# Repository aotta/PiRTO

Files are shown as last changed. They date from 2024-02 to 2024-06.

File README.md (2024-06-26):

# PiRTO

RTO-Cart porting to Raspberry PI Pico board, with on-screen menu for selecting files.

WARNING! PiRTO was developed and tested with PAL consoles, but for NTSC you need to use the .NTSC firmware that include longer delays for NTSC console

Assembly notes:
Use only 74lvc245 IC, not LVC ones are not 3,3 tolerant and may damage your Pico.
For SMD pcb version: added 3 jumper, connect 3v3 and Gnd ones, but leave open Shield jumper, connecting to Gnd seems shorting some Pico chinese clones.

Solder the microSD arduino shields on BOTTOM of the board, BEFORE you solder the Pico. Cut the pin to avoid they touche the Pico board on other sides.

Error codes (number of led flashes every second then 2 seconds pause):

1 blinks: Files too big  

2 blinks: Verify BIN files error   

3 blinks: [mapping] not found in CFG error

4 blinks: Card not initialized

5 blinks: Error opening Root

6 blinks: Map CFG error

1 blink every 800 ms is business as usual

More infor on:
https://forums.atariage.com/topic/360687-pirto-preview-new-rto-multicart-powered-by-raspberry-pico/

https://forums.atariage.com/topic/346024-intellivision-rto-multicart-new-multicart/

## Ver. 1.1 Upgrade
New version doesn't use anymore hardcoded delay in bus cycles, so it should work for every Intellivision (NTSC,PAL or SECAM).
I included the uf2 firmware in binaries folder. 
Note: with this version some games with more than 8/9 map pages (i.e. Antartic Tale, Wizard of War, etc.) don't work. Use 1.0 if you have no timing issues.

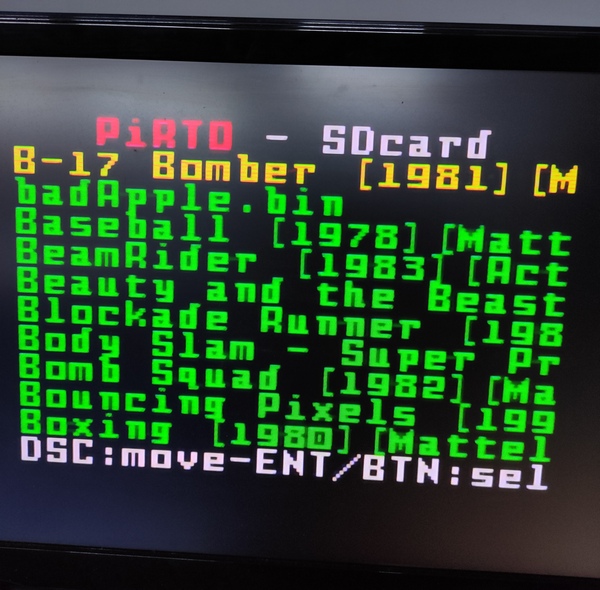
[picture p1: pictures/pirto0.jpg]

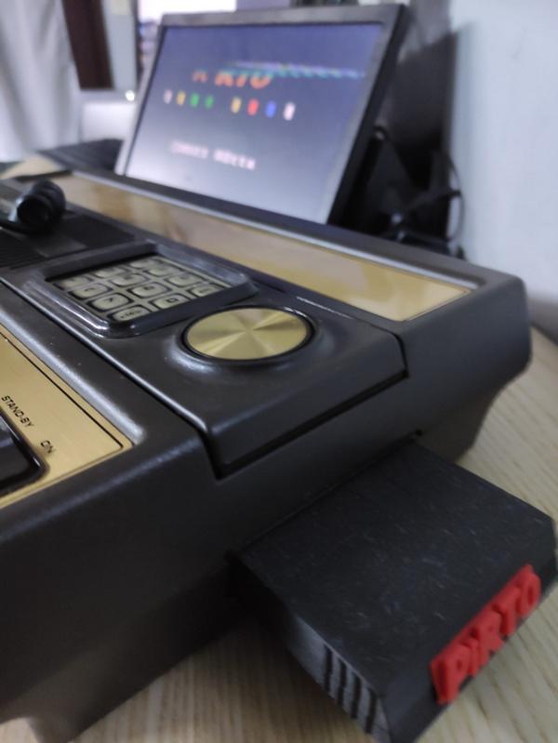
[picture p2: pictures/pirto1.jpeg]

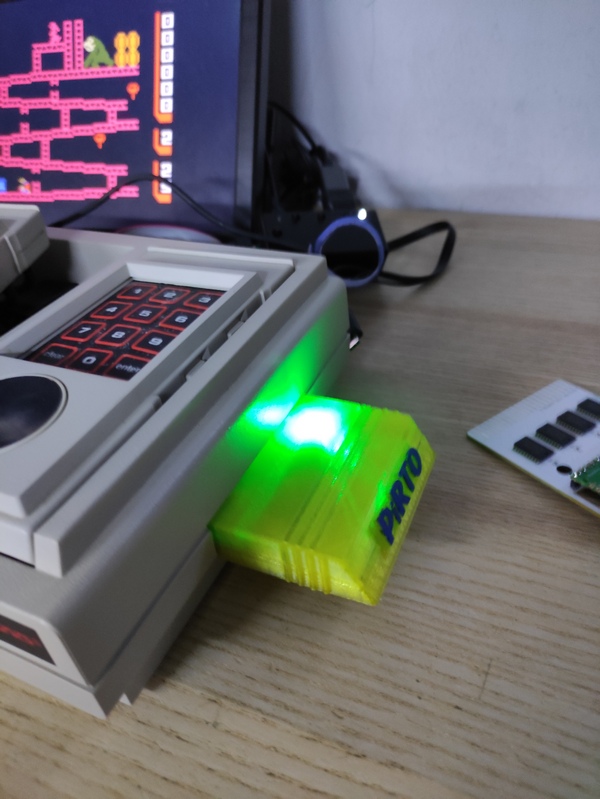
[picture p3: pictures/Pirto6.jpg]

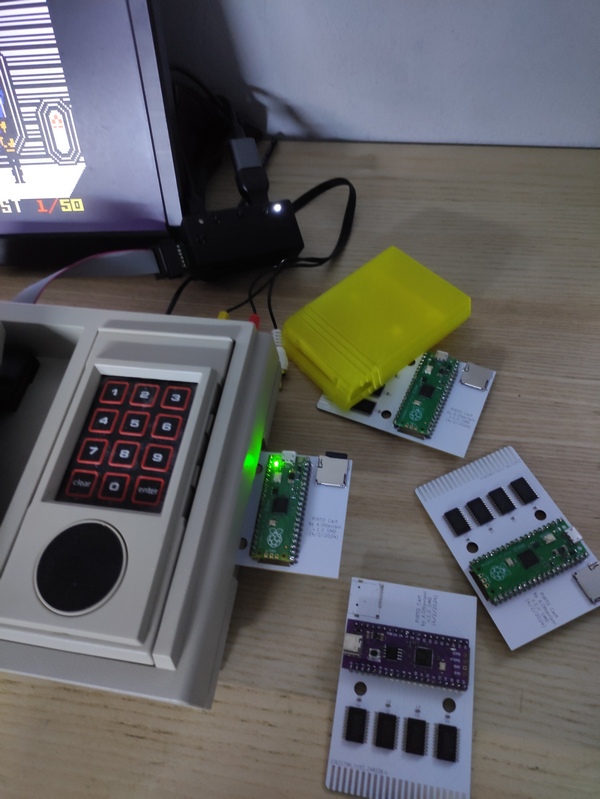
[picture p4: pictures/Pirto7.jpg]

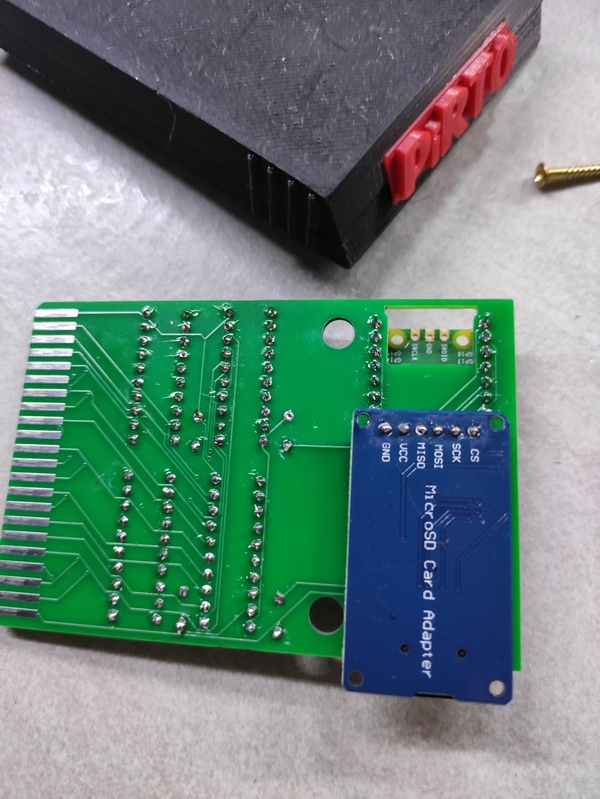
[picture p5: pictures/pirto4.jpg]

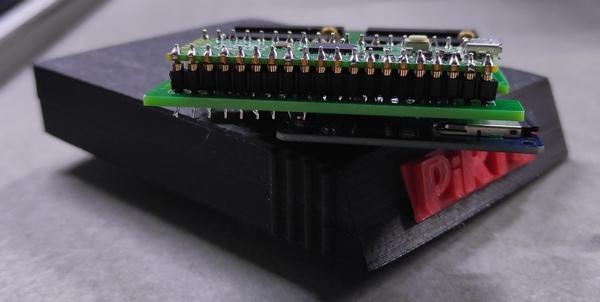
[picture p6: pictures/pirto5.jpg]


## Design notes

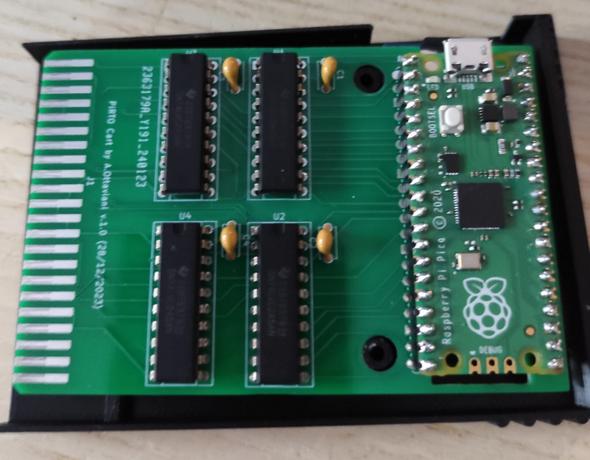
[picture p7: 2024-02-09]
pictures/pirto3.jpeg

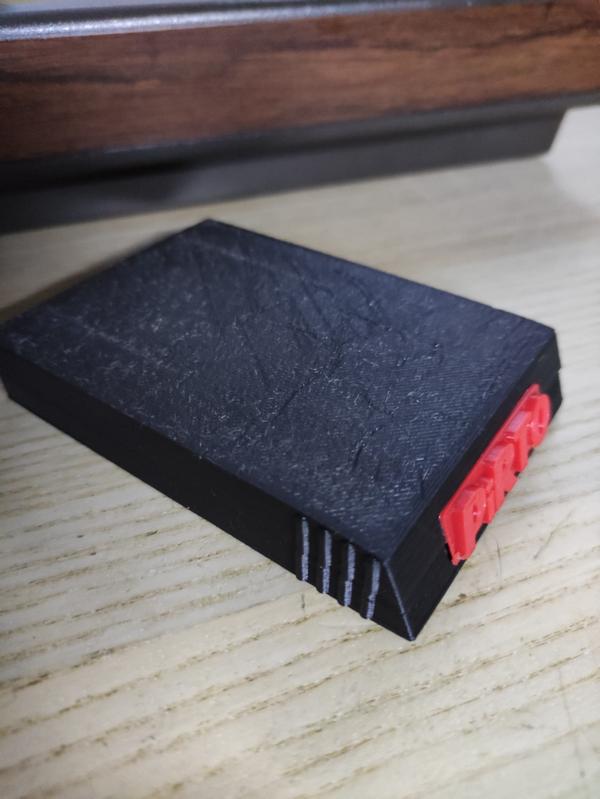
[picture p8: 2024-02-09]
pictures/pirto2.jpeg

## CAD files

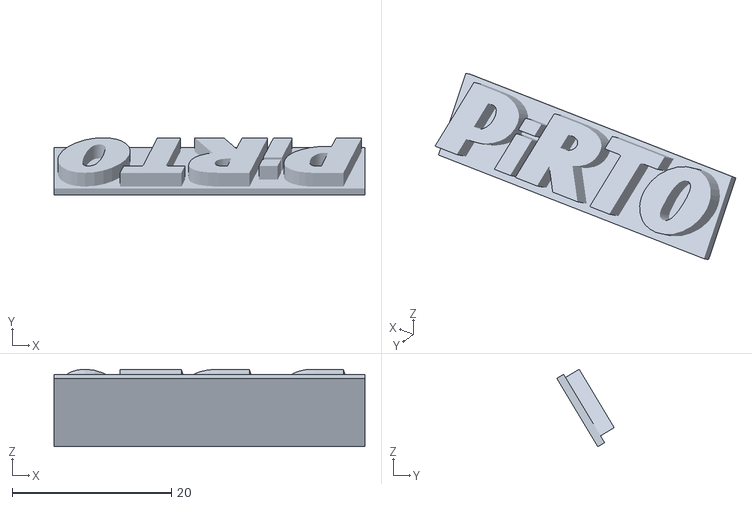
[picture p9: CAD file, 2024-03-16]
3DModel/PiRTO - SMD/PiRTO_Cart_SMD-PiRTO3d.stl
39.0 x 7.21 x 9.72

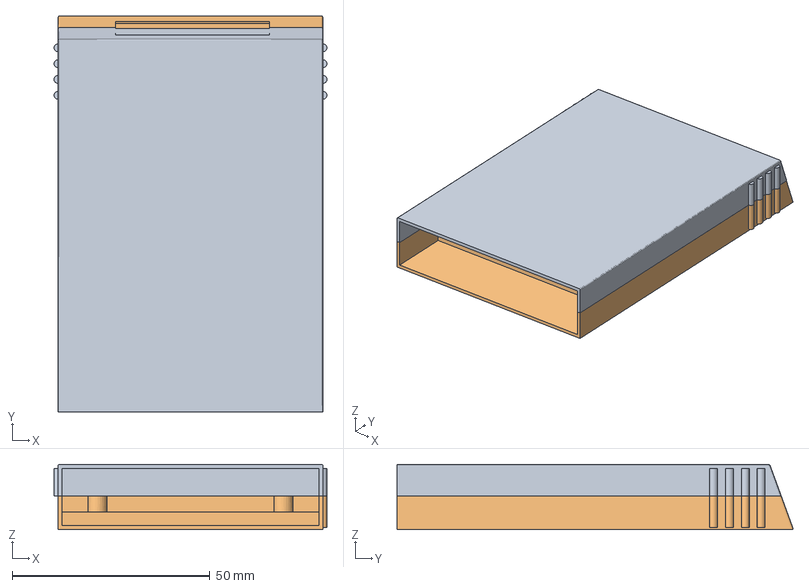
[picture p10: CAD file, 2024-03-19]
3DModel/PiRTO/PiRTO_Cart.FCStd
69.0 x 100.0 x 16.5 mm
Top (Meshed)
Base (Meshed)

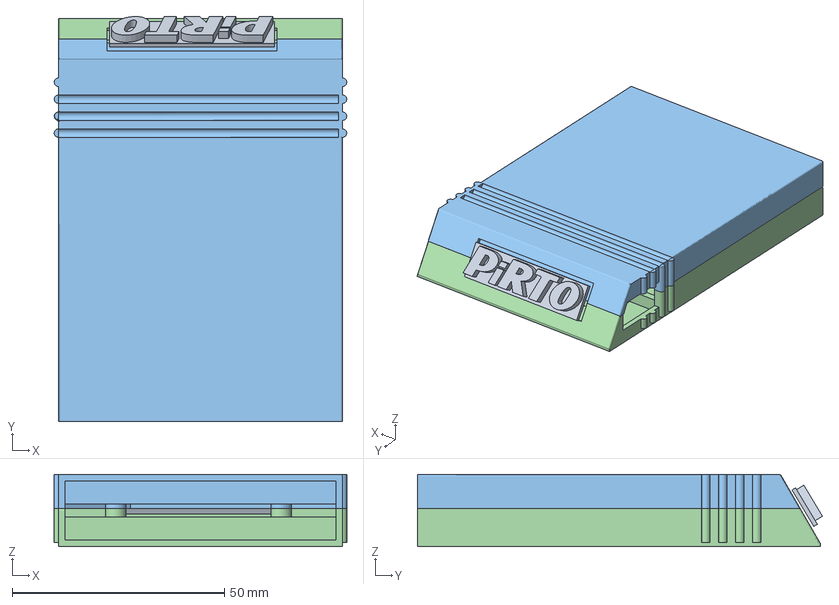
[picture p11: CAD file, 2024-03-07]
3DModel/PiRTO - SMD/PiRTO_Cart_SMD.FCStd
69.0 x 95.5 x 17.0 mm
PiRTO3d
Base3D
Top (Meshed)
Base (Meshed)

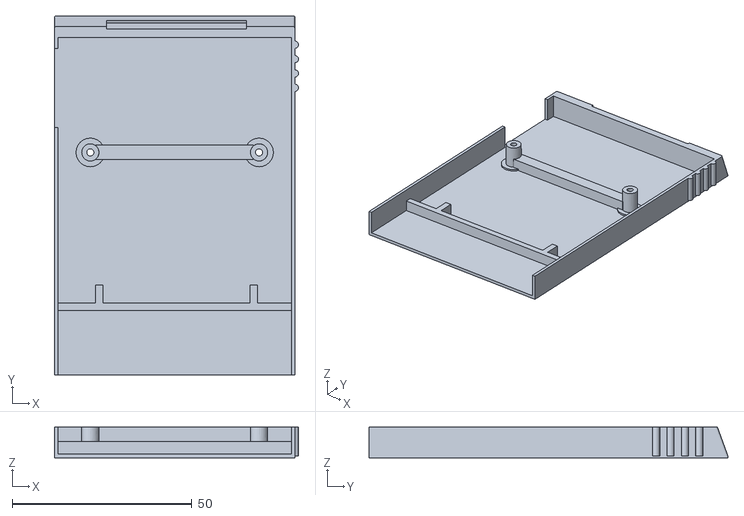
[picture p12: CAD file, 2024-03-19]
3DModel/PiRTO/PiRTO_Cart-Base3D.stl
68.0 x 100.0 x 8.50

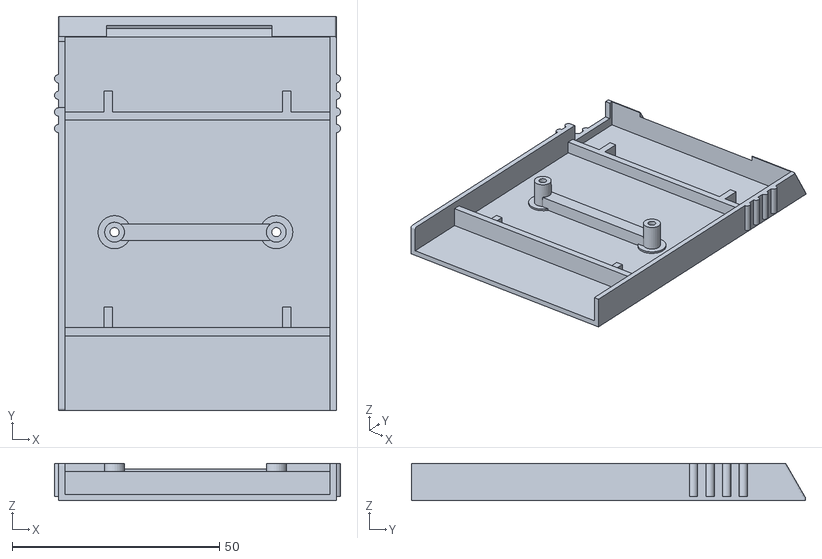
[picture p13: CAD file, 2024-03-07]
3DModel/PiRTO - SMD/PiRTO_Cart_SMD-Base3D.stl
69.0 x 95.0 x 9.00

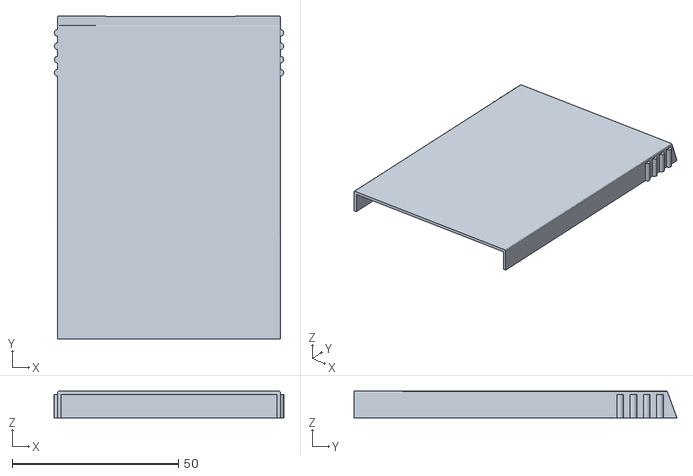
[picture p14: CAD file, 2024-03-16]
3DModel/PiRTO/PiRTO_Cart-Top3D.stl
69.0 x 97.1 x 8.00

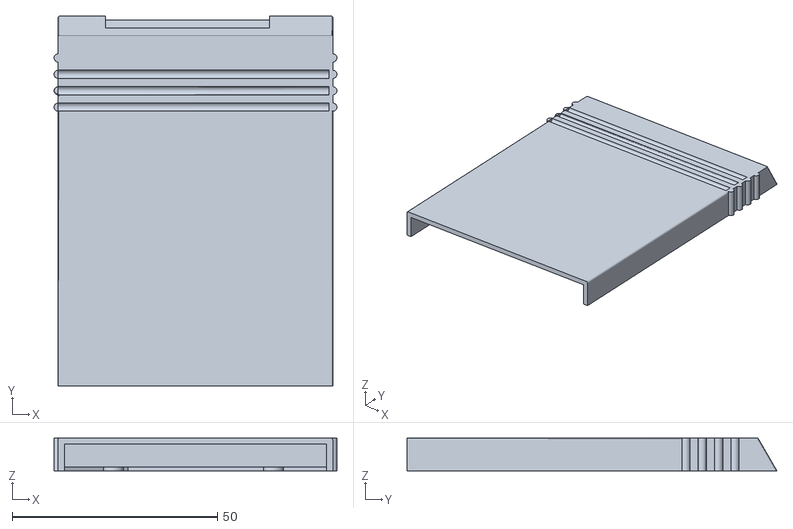
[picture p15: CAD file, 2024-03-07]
3DModel/PiRTO - SMD/PiRTO_Cart_SMD-Top3D.stl
69.0 x 90.2 x 8.00

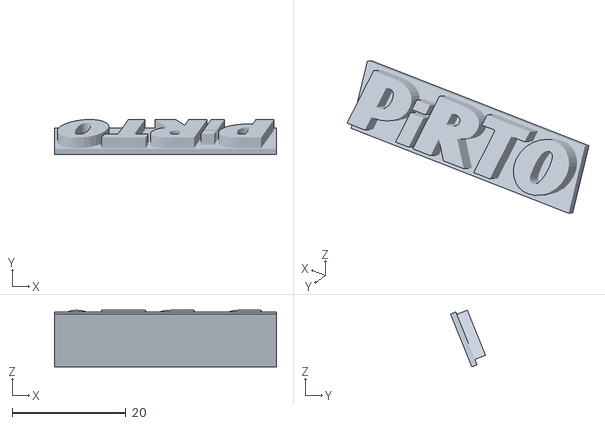
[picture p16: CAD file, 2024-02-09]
3DModel/PiRTO/PiRTO_Cart-PiRTO3d.stl
39.0 x 6.15 x 9.96

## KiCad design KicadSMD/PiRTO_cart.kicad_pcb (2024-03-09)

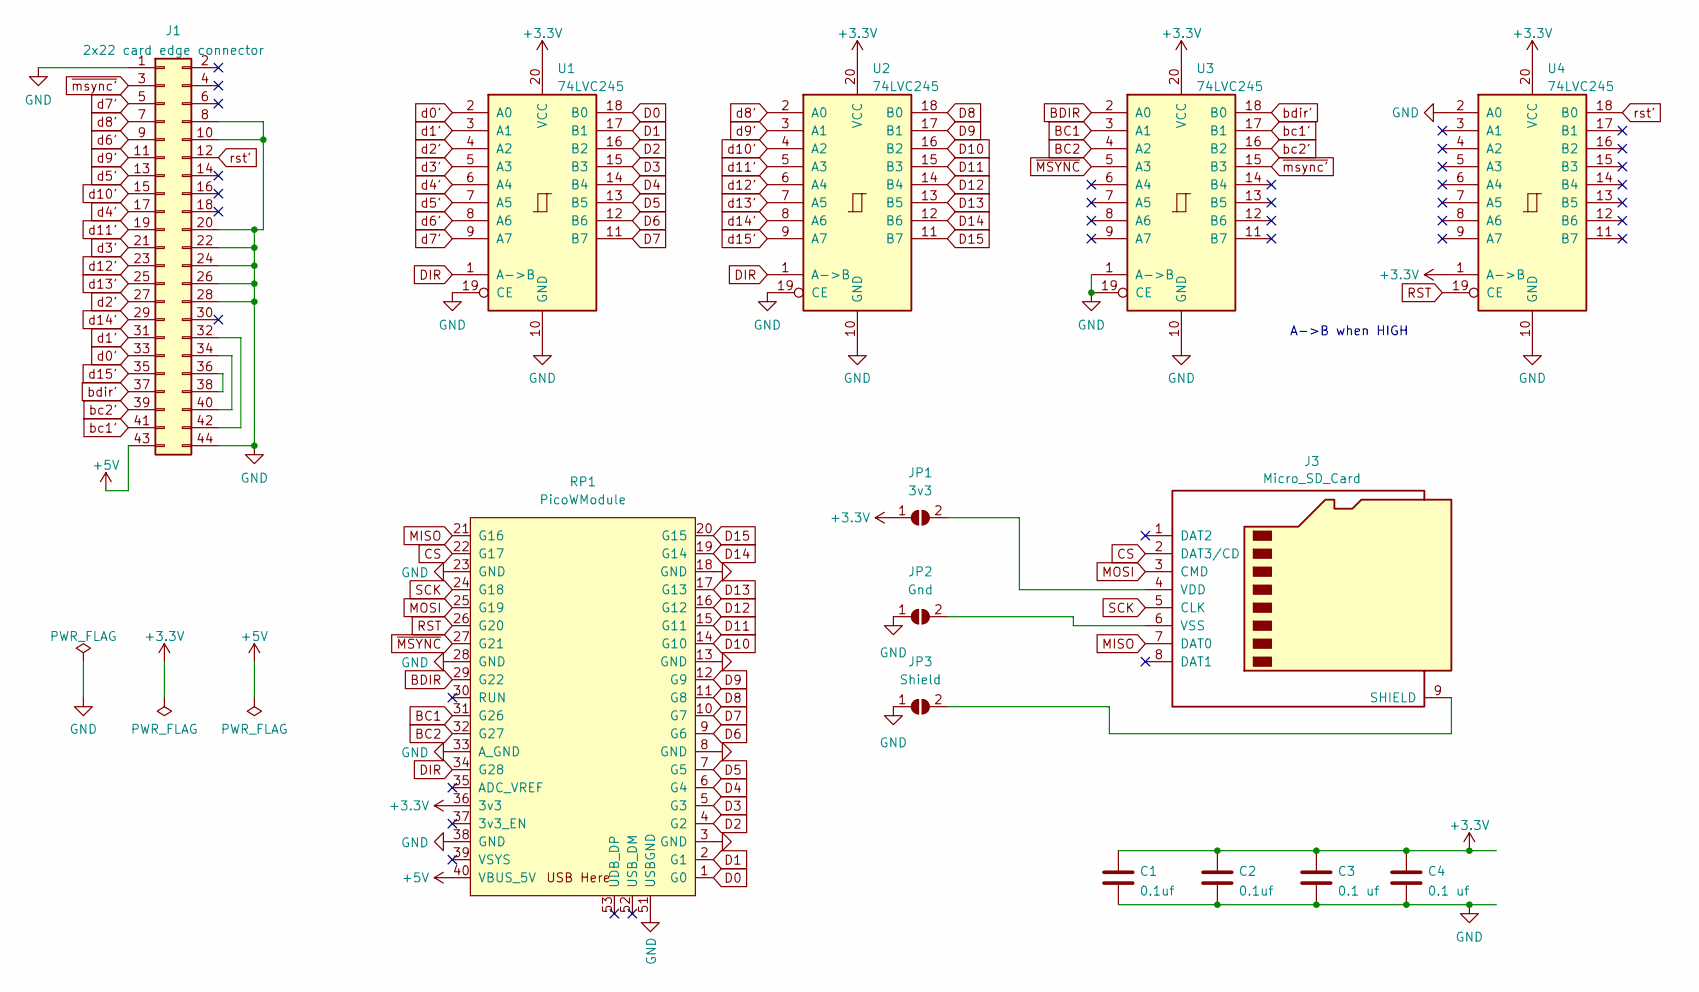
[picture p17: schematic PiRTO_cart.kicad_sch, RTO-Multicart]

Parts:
C1, C2: 0.1uf; C_0603_1608Metric
C3, C4: 0.1 uf; C_0603_1608Metric
J1: 2x22 card edge connector; edge mounted 44 pin card edge connector (2x22 pin)
J3: Micro_SD_Card; J_SD_Card-micro_socket_A
JP1: 3v3; SolderJumper-2_P1.3mm_Open_Pad1.0x1.5mm
JP2: Gnd; SolderJumper-2_P1.3mm_Open_Pad1.0x1.5mm
JP3: Shield; SolderJumper-2_P1.3mm_Open_Pad1.0x1.5mm
RP1: PicoWModule; Raspberry_Pi_PicoW_SMT_THT
U1, U2, U3, U4: 74LVC245; SOP-20_7.5x12.8mm_P1.27mm

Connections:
+3.3V: C1.1, C2.1, C3.1, C4.1, JP1.1 (A), RP1.36 (3v3), U1.20 (VCC), U2.20 (VCC), U3.20 (VCC), U4.1 (A->B), U4.20 (VCC)
+5V: J1.43, RP1.40 (VBUS_5V)
BC1: RP1.31 (G26), U3.3 (A1)
BC2: RP1.32 (G27), U3.4 (A2)
BDIR: RP1.29 (G22), U3.2 (A0)
CS: J3.2 (DAT3/CD), RP1.22 (G17)
D0: RP1.1 (G0), U1.18 (B0)
D1: RP1.2 (G1), U1.17 (B1)
D2: RP1.4 (G2), U1.16 (B2)
D3: RP1.5 (G3), U1.15 (B3)
D4: RP1.6 (G4), U1.14 (B4)
D5: RP1.7 (G5), U1.13 (B5)
D6: RP1.9 (G6), U1.12 (B6)
D7: RP1.10 (G7), U1.11 (B7)
D8: RP1.11 (G8), U2.18 (B0)
D9: RP1.12 (G9), U2.17 (B1)
D10: RP1.14 (G10), U2.16 (B2)
D11: RP1.15 (G11), U2.15 (B3)
D12: RP1.16 (G12), U2.14 (B4)
D13: RP1.17 (G13), U2.13 (B5)
D14: RP1.19 (G14), U2.12 (B6)
D15: RP1.20 (G15), U2.11 (B7)
DIR: RP1.34 (G28), U1.1 (A->B), U2.1 (A->B)
GND: C1.2, C2.2, C3.2, C4.2, J1.1, J1.8, J1.10, J1.20, J1.22, J1.24, J1.26, J1.28, J1.44, JP2.1 (A), JP3.1 (A), RP1.3 (GND), RP1.8 (GND), RP1.13 (GND), RP1.18 (GND), RP1.23 (GND), RP1.28 (GND), RP1.33 (A_GND), RP1.38 (GND), RP1.51 (USBGND), U1.10 (GND), U1.19 (CE), U2.10 (GND), U2.19 (CE), U3.1 (A->B), U3.10 (GND), U3.19 (CE), U4.2 (A0), U4.10 (GND)
MISO: J3.7 (DAT0), RP1.21 (G16)
MOSI: J3.3 (CMD), RP1.25 (G19)
unnamed: J1.32, J1.42
unnamed: J1.34, J1.40
unnamed: J1.36, J1.38
unnamed: J3.9 (SHIELD), JP3.2 (B)
unnamed: J3.4 (VDD), JP1.2 (B)
unnamed: J3.6 (VSS), JP2.2 (B)
RST: RP1.26 (G20), U4.19 (CE)
SCK: J3.5 (CLK), RP1.24 (G18)
bc1': J1.41, U3.17 (B1)
bc2': J1.39, U3.16 (B2)
bdir': J1.37, U3.18 (B0)
d0': J1.33, U1.2 (A0)
d1': J1.31, U1.3 (A1)
d2': J1.27, U1.4 (A2)
d3': J1.21, U1.5 (A3)
d4': J1.17, U1.6 (A4)
d5': J1.13, U1.7 (A5)
d6': J1.9, U1.8 (A6)
d7': J1.5, U1.9 (A7)
d8': J1.7, U2.2 (A0)
d9': J1.11, U2.3 (A1)
d10': J1.15, U2.4 (A2)
d11': J1.19, U2.5 (A3)
d12': J1.23, U2.6 (A4)
d13': J1.25, U2.7 (A5)
d14': J1.29, U2.8 (A6)
d15': J1.35, U2.9 (A7)
rst': J1.12, U4.18 (B0)
~MSYNC: RP1.27 (G21), U3.5 (A3)
~msync': J1.3, U3.15 (B3)

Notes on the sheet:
A->B when HIGH

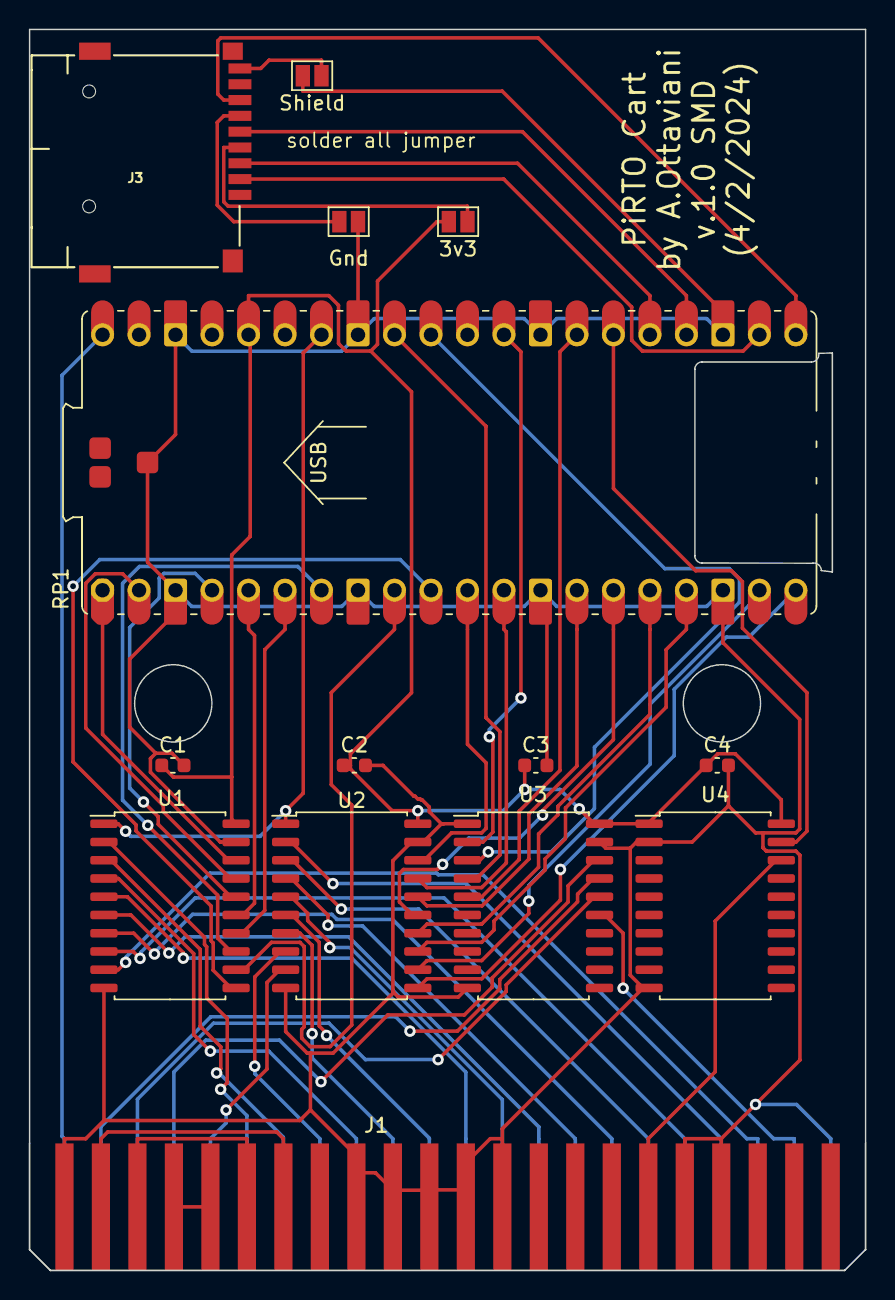
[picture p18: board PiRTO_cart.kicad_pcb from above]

Board: 2 copper layers, 58.2 x 86.4 mm, 14 parts (0 on the bottom side), 56 nets.

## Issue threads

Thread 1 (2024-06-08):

PIRTO CARD PCB analysis

Fing972, 2024-06-08:
Good morning,
First of all I would like to congratulate you on the project, I have been following a way to create a multicard cartridge for Intellivision at home for a long time.
I have already followed the project with the Teensy but I think it is too expensive and that the project can be created even with similar cheaper boards.
Coming to the point I saw that the main problem is the operation at 3.3v (PI-PICO) and 5v (Intv).
Studying the diagram I was trying to understand if it is possible to use other components instead of the 74LVC245.
I've seen other alternative components like the Cd4050 or other level shifters.
What I haven't yet understood is whether "bidirectional" communication must take place on some pins of the cartridge.
In the case of "bidirectional" communication it is necessary that if a signal arrives from the INTV(output) at 5V on a PIN of the cartridge  it must be translated to 3.3V for the PI-PICO(input), but if on the "same" PIN a signal then arrives from the PI-PICO(output) to INTV(input) must be translated from 3.3v to 5V.
If so I would understand the need to use a 74LVC245 which also has the DIR function which reverses the flow on the 8 channels. If this is not the case the project could be greatly simplified.
From what I have read the signals coming from the INTV must necessarily be converted from 5v to 3.3v for the PI-PICO. But for the reverse situation it may not be necessary to use anything since a 3.3v signal is generally identified as HIGH.
I have made a long introduction but in conclusion I would like to understand if the communication on the various PINs is unidirectional, i.e. input or output
Thanks, regards

aotta, 2024-06-08:
Level shifter is not really necessary since rp2040 can tolerate 5v input (not 5,5v, that's whay pico couldn't be defined "5V tolerant"), and PiRTO II doesn't use at all level shifters. So I simply suggest to move to PiRTO II projects, and can't consider this as an issue, so i close it.

Fing972, 2024-06-11:
Thanks for your answer,
my intention was only to comment on the project and not highlight an operating problem.
Taking advantage of the opportunity, since you mentioned the Pirto II project I just wanted to know if there was a particular reason why a PI Purple raspberry was used or if another model could be used (original or clone like yd-rp2040) naturally adapting the scheme.
I didn't know that Raspberry PI picos were 5v tolerant.
Thank you.

Closed 2024-06-08.

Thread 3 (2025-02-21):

Non-functional, looking for assistance troubleshooting

rpopp-fni-stl-com, 2025-02-21:
Hi Aotta,

Quick question regarding the Pirto.  I am having some difficulty in getting my build to work.  My soldering is correct and I ensured that I used the proper ICs.  Likewise, I have ensured there are no shorts between the 2040 and the PCB (or the underlying SD card board).

Game files are at the root of the SD card (formatted fat32) and have the recommended length <= 45, including the extension and come from the 2024 ToSEC bundle.  Those games that require a cfg file have them named the same as the bin, and have the correct memory mappings without any hacks, etc.  The root of the SD card has a 0.cfg there to act as the default config.

I am attempting to use this on a known working NTSC Intellivision II that I modified to divert (and amplify) video/audio and bypass the RF modulator.  When starting the intellivision with the cart installed, I get nothing but a black screen, and two green flashes on the 2040 (my understanding is that this is a bin verification issue).  The IC/amplifier module I used is similar to

https://www.ebay.com/itm/126632929420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

This was installed by me and is known as good and works with other game carts.

Any suggestions or hints on what I'm missing here?

aotta, 2025-02-22:
The blink (2) is the verify error.. but it's strange you got it when starting. I can only suggest you to test Pirto within Arduino IDE with USB câble connected and watch for serial output, it could help. Or, upgrading to Pirto II

rpopp-fni-stl-com, 2025-02-22:
Hrm, what, or how, do I look for?  I can compile the sketch and upload it.  Unplugging the usb cable and then reinserting it results in the ide connecting to the board at /dev/ttyACM0, but I see nothing in the serial monitor at all.  Should I not see some kind of output here?

rpopp-fni-stl-com, 2025-02-28:
@aotta Any hints here?

aotta, 2025-02-28:
The loop is for waiting an input from the pirto side, and it break when you move into menu and select a game.
If you don't get the menu on screen, your problem is somewhere before.
From your output, SDCard seems read fine and filelist sent to menu.
What if you reset the console? nothing change?
What with blind selection from joystick?

rpopp-fni-stl-com, 2025-02-28:
Hm... Resetting the console does nothing other than I see the led on the pico blink twice again.  I have tried removing and re-seating the pirto as well.  The one thing I have NOT done yet is try swapping out the controller for player 1.  I'm not as familiar with the Inty, but would it throw an error (or not boot fully) if one of the controllers wasn't plugged in?  I can't imagine it would have any sensing like that, but I may as well as ask.

aotta, 2025-02-28:
Are you sure you're using the 1.1 version? your issue may be related to sync speed with Inty II bus that affected the 1.0 version. Or, you can try the old 1.0 ntsc binary version for testing purpouse

rpopp-fni-stl-com, 2025-02-28:
I have tried both 1.0 and 1.1.  I can run a sweep through and try all of them again just to confirm if you like.

aotta, 2025-02-28:
I mean the different NTSC version 1.0 under the binaries folder, they have different timing so it could help to understand if yours it's a timing issue. I have no other hints for you, sorry, but again i suggest you to pass to the PiRTO II, is more stable, simpler and affordable. I consider the PiRTO as an obsolete project

rpopp-fni-stl-com, 2025-02-28:
Okay, I will continue to try some things before placing an order for new pcbs.  That said, is there a specific clone of the Pico that's recommended (other than just the pcb mask color ;)) to use with the II, or is there anything that can be tweaked to allow the use of the standard Pico with the II?

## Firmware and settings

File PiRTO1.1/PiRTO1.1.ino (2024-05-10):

/*
//                       PiRTO-CART by Andrea Ottaviani 
// Intellivision multicart based on Raspberry Pico board -

// v. 1.0 2023-12-28 : Initial version for Pi Pico porting of RTO-Cart for Teensy 4.1
//
// Thanks to John Dullea (dwarfaxe@yahoo.com) for his support and his ACC projects, from wich i get some bits of code
// 
//  More info on https://github.com/aotta/RTO-Cart
*/

#include "hardware/gpio.h"
#include "pico/platform.h"
#include "pico/stdlib.h"
#include "hardware/vreg.h"
#include "pico/multicore.h"
#include "pico/divider.h"
#include "hardware/flash.h"
#include "hardware/sync.h"
#include "string.h"
#include "splash.h"
#define splash_size 6144

// include for Spi cards
#include <SPI.h>
#include <SD.h>

// This are GP pins for SPI0 on the Raspberry Pi Pico board, and connect
// to different *board* level pinouts.  Check the PCB while wiring.
// Only certain pins can be used by the SPI hardware, so if you change
// these be sure they are legal or the program will crash.
// See: https://datasheets.raspberrypi.com/picow/PicoW-A4-Pinout.pdf
const int _MISO = 16;//4;  // AKA SPI RX
const int _MOSI = 19;//7;  // AKA SPI TX
const int _CS = 17;//5;
const int _SCK = 18;//6;

// include the SD library:
#include <SPI.h>
#include <SD.h>

// set up variables using the SD utility library functions:
//SdFs sd;
File root;
File entry;
File mapfile;

// Pico pin usage definitions

#define B0_PIN    0
#define B1_PIN    1
#define B2_PIN    2
#define B3_PIN    3
#define B4_PIN    4
#define B5_PIN    5
#define B6_PIN    6
#define B7_PIN    7
#define F0_PIN    8
#define F1_PIN    9
#define F2_PIN    10
#define F3_PIN    11
#define F4_PIN    12
#define F5_PIN    13
#define F6_PIN    14
#define F7_PIN    15
#define MISO_PIN  16
#define CS_PIN    17
#define SCK_PIN   18
#define MOSI_PIN  19
#define RST_PIN 20
#define MSYNC_PIN 21
#define BDIR_PIN  22
#define LED_PIN   25
#define BC1_PIN   26
#define BC2_PIN   27
#define DIR_PIN   28 // TO PIN 1 LVC245, HIGH= A->B (INPUT 5V TO 3.3V) LOW= B->A (OUTPUT 3.3V TO 5V)

int D_PIN[] ={0,1,2,3,4,5,6,7,8,9,10,11,12,13,14,15};


// Pico pin usage masks

#define B0_PIN_MASK     0x00000001L
#define B1_PIN_MASK     0x00000002L
#define B2_PIN_MASK     0x00000004L
#define B3_PIN_MASK     0x00000008L
#define B4_PIN_MASK     0x00000010L
#define B5_PIN_MASK     0x00000020L
#define B6_PIN_MASK     0x00000040L
#define B7_PIN_MASK     0x00000080L

#define F0_PIN_MASK     0x00000100L
#define F1_PIN_MASK     0x00000200L
#define F2_PIN_MASK     0x00000400L
#define F3_PIN_MASK     0x00000800L
#define F4_PIN_MASK     0x00001000L
#define F5_PIN_MASK     0x00002000L
#define F6_PIN_MASK     0x00004000L
#define F7_PIN_MASK     0x00008000L

#define MISO_PIN_MASK   0x00010000L
#define CS_PIN_MASK     0x00020000L
#define SCK_PIN_MASK    0x00040000L
#define MOSI_PIN_MASK   0x00080000L
#define RST_PIN_MASK    0x00100000L
#define MSYNC_PIN_MASK  0x00200000L
#define BDIR_PIN_MASK   0x00400000L
#define LED_PIN_MASK    0x02000000L
#define BC1_PIN_MASK    0x04000000L
#define BC2_PIN_MASK    0x08000000L
#define BC1e2_PIN_MASK  0x0C000000L
#define DIR_PIN_MASK    0x10000000L

// Aggregate Pico pin usage masks

#define BX_PIN_MASK     0x000000FFL
#define FX_PIN_MASK     0x0000FF00L
#define DATA_PIN_MASK   0x0000FFFFL
#define BUS_STATE_MASK  0x0C400000L
#define ALWAYS_IN_MASK  (BUS_STATE_MASK)
#define ALWAYS_OUT_MASK (LED_PIN_MASK)

// Inty bus values (BC2+BC1+BDIR)
// RTO Inty bus values (BDIR+BC1+BC2) ??  1 2 3 -> 2 3 1

#define BUS_NACT  0b000  //0
#define BUS_BAR   0b001  //1
#define BUS_IAB   0b100  //4
#define BUS_DWS   0b101  //5
#define BUS_ADAR  0b010  //2
#define BUS_DW    0b011  //3
#define BUS_DTB   0b110  //6
#define BUS_INTAK 0b111  //7

unsigned char busLookup[8];

// We're going to erase and reprogram a region 256k from the start of flash.
// Once done, we can access this at XIP_BASE + 256k.


char RBLo,RBHi;
#define BINLENGTH  100000L
#define RAMSIZE  0x4000
uint16_t ROM1[BINLENGTH];
uint16_t RAM[RAMSIZE];
#define maxHacks 32
uint16_t HACK[maxHacks];
uint16_t HACK_CODE[maxHacks];



unsigned int parallelBus2;
  
unsigned int romLen;
unsigned int ramfrom = 0;
unsigned int ramto =   0;
unsigned int mapfrom[80];
unsigned int mapto[80];
unsigned int maprom[80];
int mapdelta[80];
unsigned int mapsize[80];
unsigned int addrto[80];
unsigned int RAMused = 0;

unsigned int tipo[80];  // 0-rom / 1-page / 2-ram
unsigned int page[80];  // page number
int slot;
int hacks;


uint32_t selectedfile_size;    // BIN file size
char longfilename[60];         // long file name (trunked) 
char mapfilename[60];          // map cfg file name
char testfilename[60];         // for check if directory
char rewindfilename[60];       // for rewind browsing
char rewindprev[60];       // for rewind browsing
int lenfilename; 
char path[60];
char path1[60];
char tiposcelta[9];
bool pressed=false;



////////////////////////////////////////////////////////////////////////////////////
//                     Error(N)
////////////////////////////////////////////////////////////////////////////////////
void error(int numblink){
  while(1){
    for(int i=0;i<numblink;i++) {
      digitalWrite(LED_BUILTIN,HIGH);
      delay(600);
      digitalWrite(LED_BUILTIN,LOW);
      delay(500);
    }
  delay(2000);
  }
}

////////////////////////////////////////////////////////////////////////////////////
//                     REBOOT
////////////////////////////////////////////////////////////////////////////////////

void doReboot() {
  rp2040.reboot();
}

////////////////////////////////////////////////////////////////////////////////////
//                     RESET
////////////////////////////////////////////////////////////////////////////////////
void resetCart() {
  
  digitalWrite(RST_PIN,HIGH);
  delay(30);  // was 20 for Model II; 30 works for both
  digitalWrite(RST_PIN,LOW);
  delay(3);  // was 2 for Model II; 3 works for both
  while (digitalReadFast(MSYNC_PIN)==1);
  delay(1);  // was 1 for Model II
  digitalWrite(RST_PIN,HIGH);
}

////////////////////////////////////////////////////////////////////////////////////
//                     HANDLE BUS
////////////////////////////////////////////////////////////////////////////////////

void __time_critical_func(loop1()) {   //HandleBUS()
  unsigned int lastBusState, busState1;
  unsigned int busSt1, busSt2;
  unsigned int parallelBus;
  unsigned int dataOut, dataInd;
  unsigned int dataWrite=0;
  unsigned char busBit;
  bool deviceAddress = false; 
  unsigned int curPage=0;
  unsigned int checkPage=0;
  int exitBUS;
   
  busState1 = BUS_NACT;
  lastBusState = BUS_NACT;
  
  dataOut=0;

  // Main loop   

 for (int i = 0; i <= 16; i++)
  {
    gpio_init(i);  
  }
  
  gpio_init(DIR_PIN);
  gpio_init(BDIR_PIN);
  gpio_init(BC1_PIN);
  gpio_init(BC2_PIN);
  gpio_init_mask(ALWAYS_IN_MASK);
  gpio_init_mask(ALWAYS_OUT_MASK);
  
  pinMode(26,INPUT);
  pinMode(27,INPUT);
  pinMode(28,OUTPUT);
  
  gpio_set_dir_in_masked(DATA_PIN_MASK);
  gpio_set_dir_in_masked(ALWAYS_IN_MASK);
  gpio_set_dir_out_masked(ALWAYS_OUT_MASK);
 
  // Initial conditions
  
  gpio_clr_mask(DIR_PIN_MASK);

  exitBUS=1;
  
  gpio_clr_mask(DIR_PIN_MASK | DATA_PIN_MASK);
  gpio_set_dir_in_masked(DATA_PIN_MASK); // Set to input


  Serial.println("Entering main loop");
  
  while (exitBUS)
  {

  
    // Wait for the bus state to change
  
    do {
    } while (!((gpio_get_all() ^ lastBusState) & BUS_STATE_MASK));
    // We detected a change, but reread the bus state to make sure that all three pins have settled
     lastBusState = gpio_get_all();

    // busState1 = (((lastBusState >> BDIR_PIN) & 1) + ((lastBusState >> BC1_PIN) & 3)); //if gpio9    
    busSt1=((lastBusState >> BDIR_PIN) & 1);
    busSt2=((lastBusState >> BC1_PIN) & 3)*2;
    busState1=busSt1+busSt2;
    
   
    busBit = busLookup[busState1];
    // Avoiding switch statements here because timing is critical and needs to be deterministic
    if (!busBit)
    {
      // -----------------------
      // DTB
      // -----------------------
      // DTB needs to come first since its timing is critical.  The CP-1600 expects data to be
      // placed on the bus early in the bus cycle (i.e. we need to get data on the bus quickly!)
 
      if (deviceAddress)
      {
       
        // The data was prefetched during BAR/ADAR.  There isn't nearly enough time to fetch it here.
        // We can just output it.
      // Wait of 482ns 
        //delayNanoseconds(delWR);   // to tune ok a 360 / 380
        gpio_set_dir_out_masked(DATA_PIN_MASK);
        gpio_put_masked(DATA_PIN_MASK,dataOut);
        asm inline ("nop;nop;nop;nop;");
        gpio_clr_mask(DIR_PIN_MASK); 
        while(((gpio_get_all() & BC1e2_PIN_MASK)>>BC1_PIN)==3); // wait while bc1 & bc2 are high... it's enough test BC1
       
        //asm inline (delWR); //150ns
              
        gpio_set_dir_in_masked(DATA_PIN_MASK);
        gpio_set_mask(DIR_PIN_MASK);
      }
     }
    else
    {
      busBit >>= 1;
      if (!busBit)
      {
        // -----------------------
        // BAR, ADAR
        // -----------------------
       if ((deviceAddress) and (busState1==BUS_ADAR)) 
      {
        // The data was prefetched during BAR/ADAR.  There isn't nearly enough time to fetch it here.
        // We can just output it.
                
        gpio_set_dir_out_masked(DATA_PIN_MASK); // to set pins to outputs (bit0-15)
        gpio_put_masked(DATA_PIN_MASK,dataOut);
        //asm inline("nop;nop;nop");
        gpio_clr_mask(DIR_PIN_MASK); //set bus dir to output

        while((gpio_get_all() & BC1_PIN_MASK)>>BC1_PIN); //wait BC1 go down 
        //asm inline (delWR); //150ns
        
       gpio_set_dir_in_masked(DATA_PIN_MASK);
       gpio_set_mask(DIR_PIN_MASK);
      }
      /// ELSE is BAR
        // Prefetch data here because there won't be enough time to get it during DTB.
        // However, we can't take forever because of all the time we had to wait for
        // the address to appear on the bus.
        gpio_set_dir_in_masked(DATA_PIN_MASK);  // to set pins to inputs (bit 0-15)
        gpio_set_mask(DIR_PIN_MASK); //set bus dir to input   
       // We have to wait until the address is stable on the bus
        // waiting bus is stable 66 nop at 200mhz is ok/85 at 240
    
       deviceAddress = false;
      
       while(((parallelBus=gpio_get_all()) & BDIR_PIN_MASK)>>BDIR_PIN);  // wait DIR go low for finish BAR cycle 
         
       //asm inline (delRD); //150ns
          
       parallelBus = gpio_get_all()& 0xFFFF; 
       
      
       // Load data for DTB here to save time
           for (char i=0; i <= slot; i++) {
            if ((parallelBus - maprom[i]) <= mapsize[i]) {
              if (tipo[i]==0) {
                dataOut=ROM1[(parallelBus - mapdelta[i])];
                deviceAddress = true;
                break;
              }
              if (tipo[i]==1) {
                if (page[i]==curPage) {
                  dataOut=ROM1[(parallelBus - mapdelta[i])];
                  deviceAddress = true;
                  break;
                }
                if ((parallelBus & 0xfff)==0xfff) {
                  checkPage=1;
                   deviceAddress = true;
                  break;
                }
              }
              if (tipo[i]==2) {
                dataOut=RAM[parallelBus - ramfrom];
                deviceAddress = true;
                break;
              } 
            }    
          }
   
  
        if (hacks>0) {
          for (int i=0; i<maxHacks;i++) {
            if (parallelBus==HACK[i]) {
              dataOut=HACK_CODE[i];
              deviceAddress = true;
            }
            break;
          }
        } 
      }
      else
      {
         busBit >>= 1;
        if (!busBit)
        {
          // -----------------------
          // DWS
          // -----------------------
          
          if (deviceAddress) {

            gpio_set_dir_in_masked(DATA_PIN_MASK);  // to set pins to inputs (bit 0-15)
            gpio_set_mask(DIR_PIN_MASK); //set bus dir to input   
    
           
            dataWrite = gpio_get_all() & 0xFFFF; 
          
           
           if (RAMused == 1) {
             RAM[parallelBus-ramfrom]=dataWrite;
           } 
           if ((checkPage == 1) && (((dataWrite >> 4) & 0xff) == 0xA5)) {
              curPage=dataWrite & 0xf;
             // Serial.println(curPage); // Poi via!!!!!!!!!!!!!!!!!!!
              checkPage=0;
           }
           
        }
        else
        {
         // -----------------------
         // NACT, IAB, DW, INTAK
         // -----------------------
         // reconnect to bus
           parallelBus2=parallelBus;
           gpio_set_dir_in_masked(DATA_PIN_MASK);  // to set pins to inputs (bit 0-15)
           gpio_set_mask(DIR_PIN_MASK); //set bus dir to input   
    
        }
        
        }
      } 
    }    
  }
} 


////////////////////////////////////////////////////////////////////////////////////
//                     LOAD ROM
////////////////////////////////////////////////////////////////////////////////////

void loadROM() {

  
  String riga;
  char tmphex[] {0,0,0,0,0,0};
   uint8_t file_buffer[FLASH_PAGE_SIZE];
  int linepos;
  int page_counter;
  int numErr=0;
  
  strcat(path,"/");
  memcpy(path1,path,strlen(path)+1);
  Serial.print("path:");Serial.println(path);
 
  for(int i=0; i<55; i++) {
        if (longfilename[i]=='.') {
          lenfilename= i;  //dot found
        }
  }
  memcpy(mapfilename,longfilename,lenfilename);
  strcat(path1,longfilename);
  
  Serial.print("opening:");Serial.println(path1); 
  entry=SD.open(path1,FILE_READ);
  if (!entry) Serial.print("File not found:");Serial.println(path1);

  strcat(mapfilename,".cfg");
  
  strcat(path,mapfilename);
  
  mapfile=SD.open(path,FILE_READ);
  Serial.print("Map:");Serial.println(path);
  
  if (!mapfile) {
    mapfile.openNextFile();
    mapfile=SD.open("0.cfg",FILE_READ);
    Serial.println("using 0.cfg");
    }
  if (!mapfile) {
    Serial.print("Map CFG file error");
    error(6); // 6 error Map CFG
  }

  slot=0;
  hacks=0;
  RAMused=0;

  
  while (mapfile.available()) {
    riga=mapfile.readStringUntil('\n');
    Serial.println(riga);
       
    if (riga.length()>1) {
      String tmp=riga.substring(0,9);
      if (slot==0) {
        if (tmp=="[mapping]") {
          riga=mapfile.readStringUntil('\n');
        } else {
          Serial.print("[mapping] not found");
          error(3); // 3 error [mapping] section not found
        }
      }
    
      if (tmp=="[memattr]") {
        riga=mapfile.readStringUntil('\n');
        tmp=riga.substring(1,5);
        tmp.toCharArray(tmphex,5);
        ramfrom=strtoul(tmphex,NULL,16);
        mapfrom[slot]=ramfrom;
        tmp=riga.substring(9,13);
        tmp.toCharArray(tmphex,5);
        ramto=strtoul(tmphex,NULL,16);
        mapto[slot]=ramto;
        maprom[slot]=ramfrom;
        addrto[slot]=maprom[slot]+(mapto[slot]-mapfrom[slot]);
        mapdelta[slot]=maprom[slot] - mapfrom[slot];
        mapsize[slot]=mapto[slot] - mapfrom[slot];

        tipo[slot]=2; // RAM
        RAMused=1;
        slot++;
    
      } else {
        tmp=riga.substring(0,1);
        if (tmp=="p") {
          // [MACRO]
          tmp=riga.substring(2,6);
          tmp.toCharArray(tmphex,6);
          HACK[hacks]=strtoul(tmphex,NULL,16);
          tmp=riga.substring(7,10);
       
          tmp.toCharArray(tmphex,4);
          HACK_CODE[hacks]=strtoul(tmphex,NULL,16);
          Serial.print(HACK[hacks],HEX);Serial.print("-");
          Serial.println(HACK_CODE[hacks],HEX);
          hacks++;
         
        } else {
        //mapping
        linepos=riga.indexOf("-");
        if (linepos>=0) {
          tmp=riga.substring(1,linepos-1);
          tmp.toCharArray(tmphex,6);
          mapfrom[slot]=strtoul(tmphex,NULL,16);
          tmp=riga.substring(linepos+3,linepos+9);
          tmp.toCharArray(tmphex,6);
          mapto[slot]=strtoul(tmphex,NULL,16);
          if (linepos==6) {
            tmp=riga.substring(linepos+11,linepos+15);
          } else {
            tmp=riga.substring(linepos+12,linepos+17);
          }
          tmp.toCharArray(tmphex,6);
          maprom[slot]=strtoul(tmphex,NULL,16);
          if (linepos==6) {
            tmp=riga.substring(22,26);
          } else {
            tmp=riga.substring(24,28);
          }  
          tmp.toCharArray(tmphex,6);
          addrto[slot]=maprom[slot]+(mapto[slot]-mapfrom[slot]);
          if (!(strcmp(tmphex,"PAGE"))) {
            tipo[slot]=1;
            if (linepos==6) {
              tmp=riga.substring(27,28);
            } else {
              tmp=riga.substring(29,31);
            }   
          tmp.toCharArray(tmphex,2);
          page[slot]=strtoul(tmphex,NULL,16);
          } else {
            tipo[slot]=0;
          }
          slot++;
          }
        }
        mapdelta[slot-1]=maprom[slot-1] - mapfrom[slot-1];
        mapsize[slot-1]=mapto[slot-1] - mapfrom[slot-1];

        Serial.print("Slot:");Serial.print(slot-1);
        Serial.print("-From:");Serial.print(mapfrom[slot-1],HEX);
        Serial.print(" to:");Serial.print(mapto[slot-1],HEX);
        Serial.print(" IN:");Serial.print(maprom[slot-1],HEX);
        Serial.print(" tipo:");Serial.print(tipo[slot-1]);
        Serial.print(" page:");Serial.print(page[slot-1]);
        Serial.print(" addr-to:");Serial.print(addrto[slot-1],HEX);
        Serial.print(" delta:");Serial.print(mapdelta[slot-1],DEC);
        Serial.print(" size:");Serial.println(mapsize[slot-1],DEC);

        }
     }
  }
  

  RAM[0x1111]=1;
  RAM[0x651]=0;
  delay(50);
  if (hacks>0) {
    Serial.println("HACKs Found!");
  }

  slot--;  // conservo il numero di slot!

  Serial.print("Slots:");Serial.println(slot);
  
  if (entry) {
    // read from the file until there's nothing else in it:
    romLen=0;
    while (entry.available()) {
      RBHi = entry.read();
      RBLo = entry.read();
      unsigned int dataW= RBLo | (RBHi << 8);
      ROM1[romLen]=dataW;
      romLen++;
         if (romLen>BINLENGTH) {
       Serial.println("File too big!");
          error(1); // 1 file too big
          while(1);
      }
    }
   Serial.print("Rom lenght:");Serial.println(romLen,DEC);
  //verify
  //  slot=0;
    romLen=0;
    entry.seek(0);
    while (entry.available()) {
      RBHi=entry.read();
      RBLo=entry.read();
      unsigned int dataW= RBLo | (RBHi << 8);
      //fileOffset=romLen - mapfrom[slot] + maprom[slot];
      if (ROM1[romLen]!= dataW) {
        Serial.print("@:");Serial.print(romLen,HEX);Serial.print("-");
        Serial.print(ROM1[romLen],HEX);Serial.print("-");Serial.println(dataW,HEX);
        numErr++;
      } 
      romLen++;
     } 
     Serial.print("Rom lenght:");Serial.println(romLen,DEC);
    // close the file:
    entry.close();
  } else {
    // if the file didn't open, print an error:
          Serial.print("Verify error 2");
          error(2);
  return; 
  Serial.print("Rom lenght:");Serial.println(romLen-1);
  }
  if (numErr!=0) {
    Serial.print("Verify error n. ");Serial.println(numErr);
    error(2); // 2 error Verify rom 
  } else {
    Serial.println("Verify OK");
  }

}
 
////////////////////////////////////////////////////////////////////////////////////
//                     MENU INTELLIVISION
////////////////////////////////////////////////////////////////////////////////////    
#pragma GCC push_options
#pragma GCC optimize ("O0")
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
void loop() 

{
  int i=0;
  
  // Initialize GPIO pins
  while (i<=40) {
    digitalWrite(LED_BUILTIN,HIGH);
    delay(800);
    Serial.print(parallelBus2,HEX);
    Serial.print("-");
    digitalWrite(LED_BUILTIN,LOW);
  delay(800);
  i++;
  }
  Serial.println("");
  i=0;

  
 }

////////////////////////////////////////////////////////////////////////////////////
//                     MAIN LOOP
////////////////////////////////////////////////////////////////////////////////////    
  
void setup1()
{
  delay(480);

 
}

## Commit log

2024-02-11 Add files via upload
    changed high of basement under the pcb to 4mm
    [PiRTO_Cart-Base3D.stl, PiRTO_Cart.FCStd]
2024-02-20 Delete PiRTO_Cart-Base3D.stl
    wrong dir
    [PiRTO_Cart-Base3D.stl]
2024-02-23 Add files via upload
    SMD version of pcb
2024-02-23 Add files via upload
    included bom & pos for pcb production
2024-03-06 Delete GERBER-PiRTO_SMD_cart.zip
    now working at the moment...
2024-03-07 Add files via upload
    added little overvoltage (1.15 volt) for better stability
    [PiRTO1.0.ino]
2024-03-07 Create gerbers
2024-03-19 Add files via upload
    added cr by Tissemon for skipping Mac system files
    [PiRTO1.0.ino]
2024-05-02 Add files via upload
    bug fixed
    [PiRTO1.1.ino]
2024-05-02 Add files via upload
    a further bug removed
    [PiRTO1.1.ino]
2024-05-10 Add files via upload
    fixed bug in ram pages (chess game)
    [PiRTO1.1.ino]
